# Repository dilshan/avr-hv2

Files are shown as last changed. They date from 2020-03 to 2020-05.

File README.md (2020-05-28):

AVR High Voltage Programmer 2
==========================

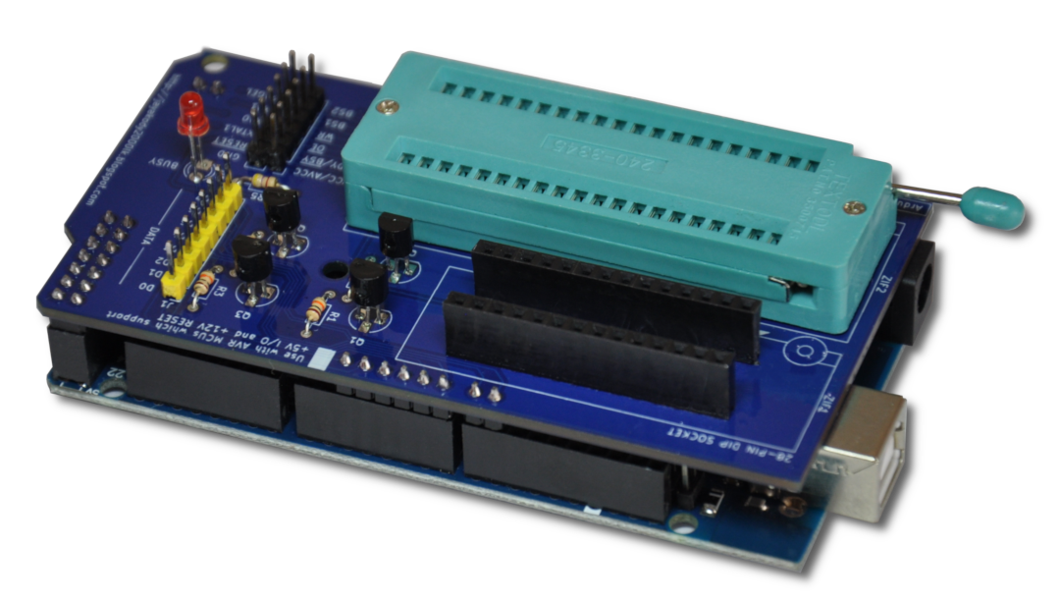
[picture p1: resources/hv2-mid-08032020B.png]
AVR-HV2 Prototype with Arduino MEGA board


*AVR-HV2* is *Arduino* based high voltage parallel programmer for *[AVR](https://www.microchip.com/design-centers/8-bit/avr-mcus)* microcontrollers. This programmer can read, write, and erase both flash memory and EEPROM. Also, this can use to set fuse bits of *AVR* MCUs. 

*AVR-HV2* programmer is designed as an *[Arduino Mega](https://www.arduino.cc/en/Main/ArduinoBoardMega2560)* shield. Dimensions of the *AVR-HV2* are similar to the *Arduino Mega* board. It can be powered using a power source connected to the *Arduino Mega* board. The suggested power source for this programmer is a 12V 1A DC power adapter. 

The control software of this programmer is design to work on both *Windows* and *Linux* operating systems. It supports the import and export of memory data in the Intel hex file format. The communication link between the programmer and the control software is established through the USB port. 

The current firmware and control software of this programmer supports most of the generally available *AVR* MCUs which including *ATmega8*, *ATmega328*, *ATmega32*, *ATmega16*, etc. The *AVR* MCUs with extended addressing modes are currently not supported. 

The PCB board used in this project is sponsored by the *[PCBWay](https://www.pcbway.com/)*. PCB of this project can directly order from *PCBWay* through this [link](https://www.pcbway.com/project/shareproject/AVR_High_Voltage_Programmer_2.html).

This is a certified open-source hardware project. All the design files, [documentation](https://github.com/dilshan/avr-hv2/wiki) and firmware source code are available to [download](https://github.com/dilshan/avr-hv2/releases) at the project source repository. All the content of this project are distributed under the terms of the following license:

- Hardware License: [CC BY 4.0](https://creativecommons.org/licenses/by/4.0/)
- Software License: [MIT](https://github.com/dilshan/avr-hv2/blob/master/LICENSE)
- Documentation License: [CC BY 4.0](https://creativecommons.org/licenses/by/4.0/)

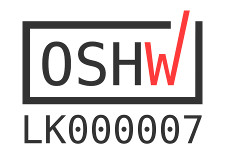
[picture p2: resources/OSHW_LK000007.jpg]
OSHW-LK000007 (https://certification.oshwa.org/lk000007.html)


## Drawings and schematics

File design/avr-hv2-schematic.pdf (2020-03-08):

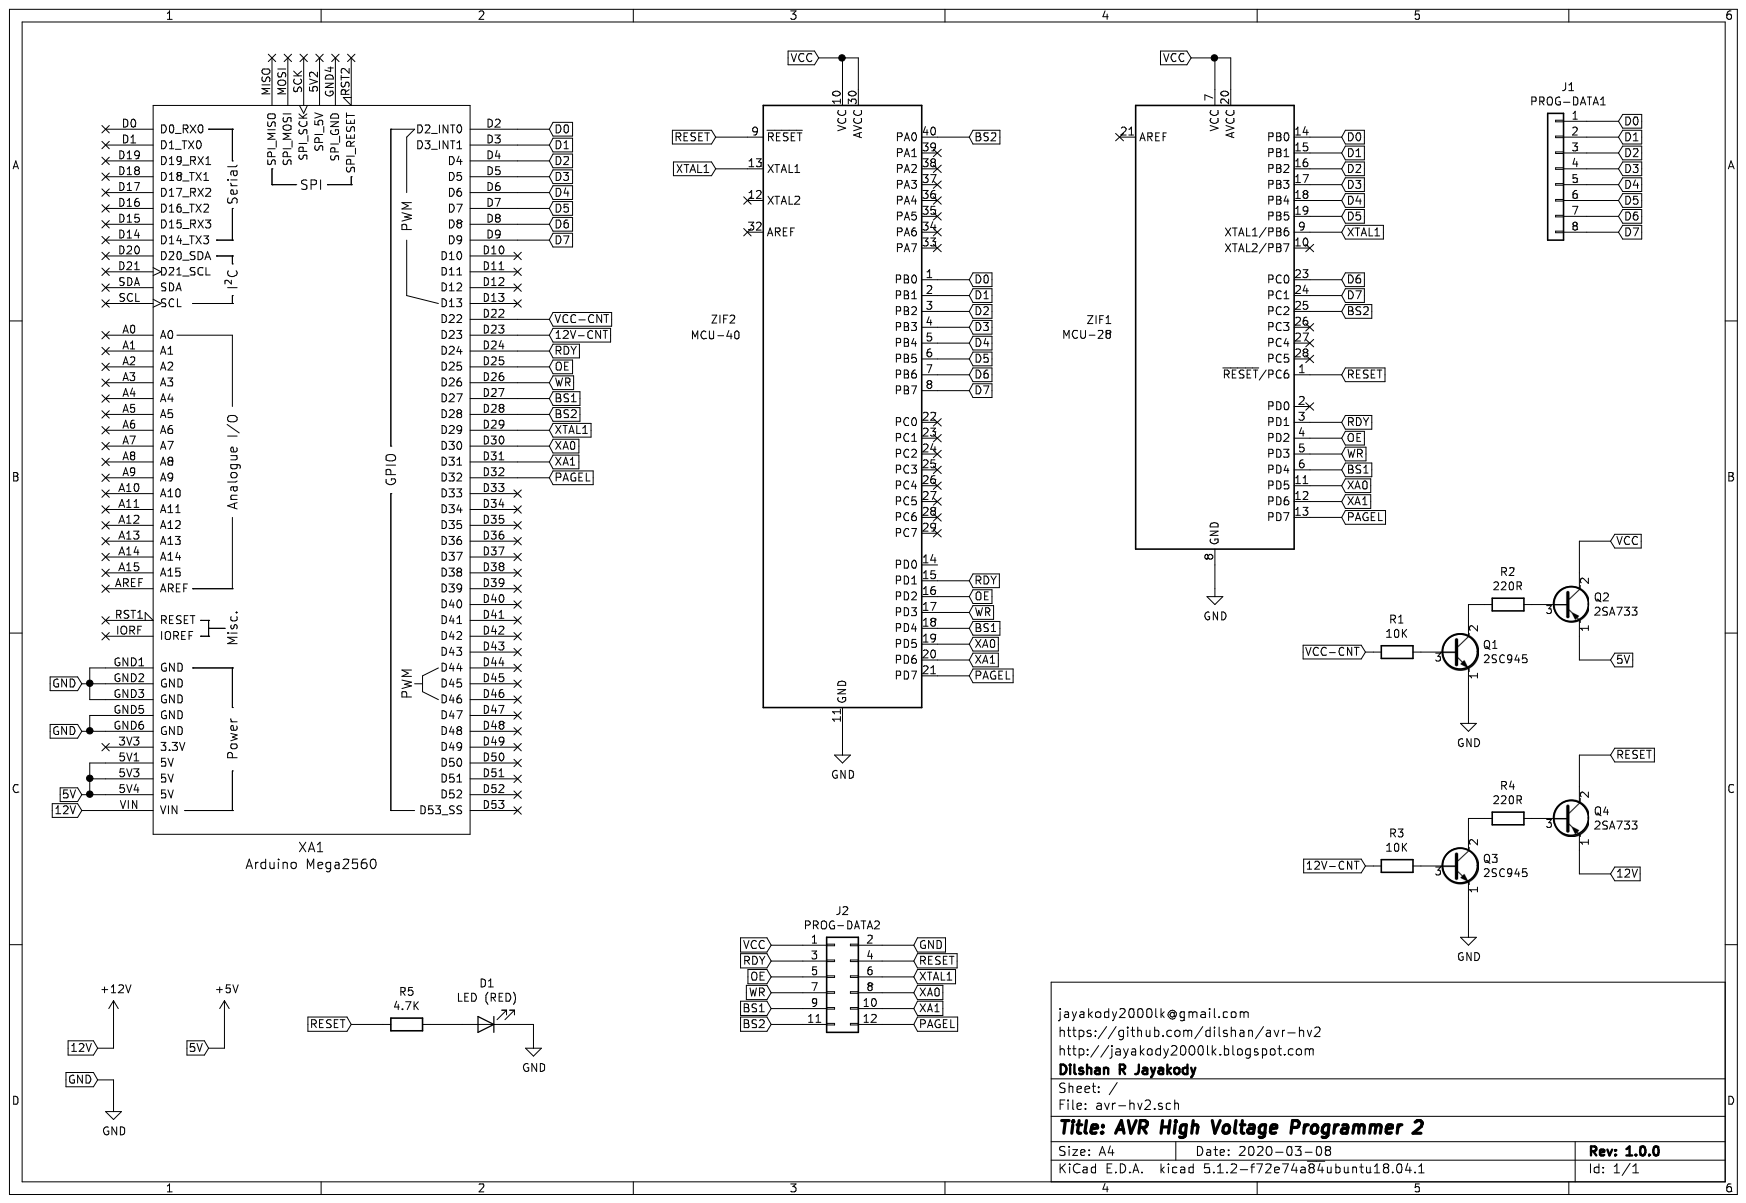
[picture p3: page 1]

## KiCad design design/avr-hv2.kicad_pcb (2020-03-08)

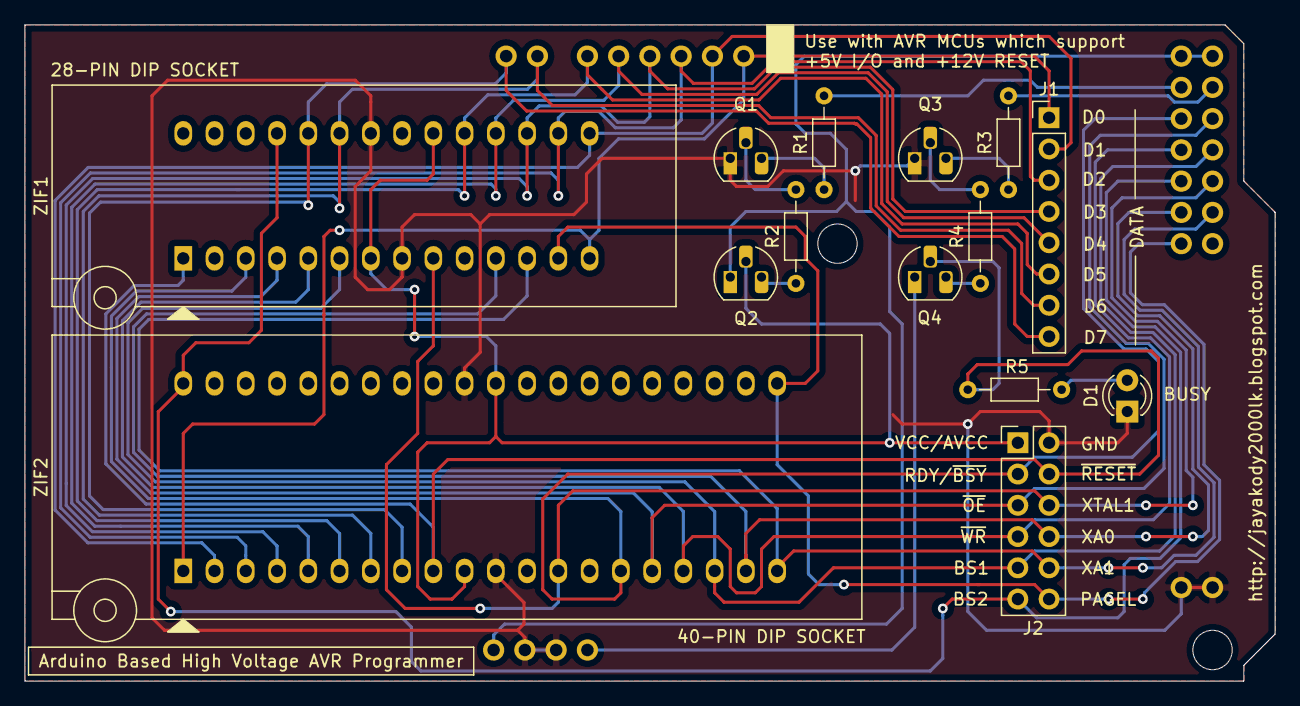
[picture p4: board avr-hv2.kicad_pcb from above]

Board: 2 copper layers, 101.6 x 53.3 mm, 15 parts (0 on the bottom side), 31 nets.

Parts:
D1: LED (RED); LED_D3.0mm
J1: PROG-DATA1; PinHeader_1x08_P2.54mm_Vertical
J2: PROG-DATA2; PinHeader_2x06_P2.54mm_Vertical
Q1, Q3: 2SC945; TO-92_HandSolder
Q2, Q4: 2SA733; TO-92_HandSolder
R1, R3: 10K; R_Axial_DIN0204_L3.6mm_D1.6mm_P7.62mm_Horizontal
R2, R4: 220R; R_Axial_DIN0204_L3.6mm_D1.6mm_P7.62mm_Horizontal
R5: 4.7K; R_Axial_DIN0204_L3.6mm_D1.6mm_P7.62mm_Horizontal
XA1: Arduino Mega2560; MEGA2560
ZIF1: MCU-28; DIP_Socket-28_W6.9_W7.62_W10.16_W12.7_W13.5_3M_228-4817-00-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
ZIF2: MCU-40; DIP_Socket-40_W11.9_W12.7_W15.24_W17.78_W18.5_3M_240-1280-0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

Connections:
5V: Q2.1, XA1.5V1, XA1.5V3, XA1.5V4
12V: Q4.1, XA1.VIN
12V-CNT: R3.2, XA1.D23
BS1: J2.9, XA1.D27, ZIF1.6, ZIF2.18
BS2: J2.11, XA1.D28, ZIF1.25, ZIF2.40
D0: J1.1, XA1.D2, ZIF1.14, ZIF2.1
D1: J1.2, XA1.D3, ZIF1.15, ZIF2.2
D2: J1.3, XA1.D4, ZIF1.16, ZIF2.3
D3: J1.4, XA1.D5, ZIF1.17, ZIF2.4
D4: J1.5, XA1.D6, ZIF1.18, ZIF2.5
D5: J1.6, XA1.D7, ZIF1.19, ZIF2.6
D6: J1.7, XA1.D8, ZIF1.23, ZIF2.7
D7: J1.8, XA1.D9, ZIF1.24, ZIF2.8
GND: D1.1, J2.2, Q1.1, Q3.1, XA1.GND2, XA1.GND3, XA1.GND5, XA1.GND6, ZIF1.8, ZIF1.22, ZIF2.11, ZIF2.31
unnamed: D1.2, R5.1
unnamed: Q1.2, R2.2
unnamed: Q1.3, R1.1
unnamed: Q2.3, R2.1
unnamed: Q3.2, R4.2
unnamed: Q3.3, R3.1
unnamed: Q4.3, R4.1
OE: J2.5, XA1.D25, ZIF1.4, ZIF2.16
PAGEL: J2.12, XA1.D32, ZIF1.13, ZIF2.21
RDY: J2.3, XA1.D24, ZIF1.3, ZIF2.15
RESET: J2.4, Q4.2, R5.2, ZIF1.1, ZIF2.9
VCC: J2.1, Q2.2, ZIF1.7, ZIF1.20, ZIF2.10, ZIF2.30
VCC-CNT: R1.2, XA1.D22
WR: J2.7, XA1.D26, ZIF1.5, ZIF2.17
XA0: J2.8, XA1.D30, ZIF1.11, ZIF2.19
XA1: J2.10, XA1.D31, ZIF1.12, ZIF2.20
XTAL1: J2.6, XA1.D29, ZIF1.9, ZIF2.13

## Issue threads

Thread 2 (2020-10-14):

FYI: repurposed to program ATtiny28 via ATmega4809 (on protoboard.)

WestfW, 2020-10-14:
(no, this isn't really an "issue.")

It happens that I have some ATtiny28 chips that I want to program.
These are only programmable via HVPP, and my STK500 doesn't seem to be working, so I looked around for something else that might be able to program it, and found your avr-hv2 project.

I based the hardware (built on a protoboard) on your project, plus the datasheet, plus some other HV programmers, and started with your firmware.  I don't think that much of it is left - the ATtiny28 works somewhat differently, I didn't try to make it more general, I used an ATmega4809 board as the programmer, and I implemented a more user-oriented communications protocol, but I wanted to thank you for publishing your project, since it was definitely easier to start working with it than to start from nothing...

Should you need to program a very old HVPP chip, it might be useful to look at.  It's here:  https://github.com/WestfW/Duino-hacks/tree/master/hvTiny28prog

Thanks!

dilshan, 2020-10-14:
Hello @WestfW.

Thank you for share this information.

I had limited experience with the ATTiny family because it is not much popular here (in _Sri Lanka_). At the time of this development, ATTiny chips are hard to find in the market. That's the main reason I skip ATTiny support.

It's good to have HVPP support programmer firmware for the ATTiny family. Most of the time, I need these HVPPs to recover the chips, which got "bricked" by wrong fuse settings.

Thank you! :+1:

Closed 2020-10-14.

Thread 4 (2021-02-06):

Atmega644p fuse fixing

mossana, 2021-02-06:
Hello
I programmer a atmega644p and set fuse cksel[3-0]=0001
And my arduino as isp can't detect chip again by avrdude
So can avr-hv2 solve problem or not ?
Thank you 😊 for your help

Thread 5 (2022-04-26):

Support for Attiny 2313a and 4313

thecky, 2022-04-26:
Hi,

is it possible to add the definitions for the:
 * Attiny 2313a
 * Attiny 4313

to the main-programm?

This both devices support HVPP and I would like to use avr-hv2 with this MCU.
The datasheet can be found here:
https://ww1.microchip.com/downloads/en/DeviceDoc/doc8246.pdf

Thank you.

W4DJW, 2023-09-08:
Hi,

Is it possible to add the definitions for the ATtiny28 L/V to the main-program?

This device supports HVPP and I would like to use the avr-hv2 with this MCU. Looking for the Flash Page size,  number of pages and Fuse bit updates. I'm not finding any info in the datasheet.

In addition, is there a way to update Fuse bytes from data I entered in the 'Configuration' tab?

Last thing, the 'Erase Chip' button appears to do nothing with respect to stored values. I can read the flash and get the same results with the chip in the socket or removed from the socket.

The ATtiny28 datasheet can be found here:

   https://ww1.microchip.com/downloads/en/DeviceDoc/doc1062.pdf

Thank you.

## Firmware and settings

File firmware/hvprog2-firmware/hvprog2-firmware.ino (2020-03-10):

/*==============================================================================

  Arduino based AVR High Voltage Programmer 2
  [https://github.com/dilshan/avr-hv2]

  Copyright (c) 2020 Dilshan R Jayakody [jayakody2000lk at gmail dot com]

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
  THE SOFTWARE IS PROVIDED "AS IS", WITHOUT WARRANTY OF ANY KIND, EXPRESS OR
  IMPLIED, INCLUDING BUT NOT LIMITED TO THE WARRANTIES OF MERCHANTABILITY,
  FITNESS FOR A PARTICULAR PURPOSE AND NONINFRINGEMENT. IN NO EVENT SHALL THE
  AUTHORS OR COPYRIGHT HOLDERS BE LIABLE FOR ANY CLAIM, DAMAGES OR OTHER
  LIABILITY, WHETHER IN AN ACTION OF CONTRACT, TORT OR OTHERWISE, ARISING FROM,
  OUT OF OR IN CONNECTION WITH THE SOFTWARE OR THE USE OR OTHER DEALINGS IN THE
  SOFTWARE.
==============================================================================*/

#define RX_BUFFER_SIZE  4

#define CMD_HANDSHAKE       'H'
#define CMD_VERSION         'V'
#define CMD_CHIP_SIGNATURE  'S'
#define CMD_GET_FUSE        'A'
#define CMD_GET_CALIBRATE   'L'
#define CMD_READ_FLASH      'R'
#define CMD_END             'E'
#define CMD_ERASE           'C'
#define CMD_WRITE_FLASH     'W'
#define CMD_WRITE_PAGE      'P'
#define CMD_READ_EEPROM     'T'
#define CMD_WRITE_EEPROM    'J'
#define CMD_WRITE_E2PAGE    'X'
#define CMD_SET_FUSE_LOW    'B'
#define CMD_SET_FUSE_HIGH   'I'
#define CMD_SET_FUSE_EXT    'K'
#define CMD_SET_FUSE_LOCK   'O'

#define PIN_VCC             22
#define PIN_12V             23

#define PIN_RDY             24
#define PIN_OE              25
#define PIN_WR              26
#define PIN_BS1             27
#define PIN_BS2             28
#define PIN_XTAL1           29
#define PIN_XA0             30
#define PIN_XA1             31
#define PIN_PAGEL           32

#define PIN_D0              2
#define PIN_D1              3
#define PIN_D2              4
#define PIN_D3              5
#define PIN_D4              6
#define PIN_D5              7
#define PIN_D6              8
#define PIN_D7              9

#define PROG_ENABLE0        PIN_BS1
#define PROG_ENABLE1        PIN_XA0
#define PROG_ENABLE2        PIN_XA1
#define PROG_ENABLE3        PIN_PAGEL

#define loadAddressLow(a) loadAddress(LOW, a)
#define loadAddressHigh(a) loadAddress(HIGH, a)

#define loadDataLow(d) loadData(LOW, d)
#define loadDataHigh(d) loadData(HIGH, d)

const unsigned char charMap[16] = {0x30, 0x31, 0x32, 0x33, 0x34, 0x35, 0x36, 0x37, 0x38, 0x39, 0x61, 0x62, 0x63, 0x64, 0x65, 0x66};

char commandBuffer[RX_BUFFER_SIZE];
unsigned char commandPos;
unsigned char lastCommand = ' ';

void resetBuffer()
{
  // Clear command buffer.
  for(unsigned char tmpPos = 0; tmpPos < RX_BUFFER_SIZE; tmpPos++)
  {
    commandBuffer[tmpPos] = 0;    
  }

  commandPos = 0;
}

void sendCommandResponse(char cmd, char error, char dataLen)
{
  char responseData[] = {'@', cmd, error, dataLen};
  Serial.write(responseData, 4);  
}

void byteToChr(unsigned char inByte, unsigned char *out)
{
  out[0] = charMap[(inByte >> 4) & 0x0F];
  out[1] = charMap[inByte & 0x0F];
}

void chrToByte(unsigned char *chrBuffer, unsigned char* byteData)
{
  byteData[0] = (((chrBuffer[0] < 58) ? (chrBuffer[0] - 48) : (chrBuffer[0]) - 87) << 4) 
  | ((chrBuffer[1] < 58) ? (chrBuffer[1] - 48) : (chrBuffer[1] - 87));
}

void chrToWord(unsigned char *chrBuffer, unsigned char* wordData)
{
  wordData[0] = (((chrBuffer[0] < 58) ? (chrBuffer[0] - 48) : (chrBuffer[0]) - 87) << 4) 
  | ((chrBuffer[1] < 58) ? (chrBuffer[1] - 48) : (chrBuffer[1] - 87));
  wordData[1] = (((chrBuffer[2] < 58) ? (chrBuffer[2] - 48) : (chrBuffer[2]) - 87) << 4) 
  | ((chrBuffer[3] < 58) ? (chrBuffer[3] - 48) : (chrBuffer[3] - 87));  
}

void chrToWriteWord(unsigned char *chrBuffer, unsigned char* wordData)
{
  wordData[0] = (((chrBuffer[0] < 58) ? (chrBuffer[0] - 48) : (chrBuffer[0]) - 87) << 4) 
  | ((chrBuffer[1] < 58) ? (chrBuffer[1] - 48) : (chrBuffer[1] - 87));
  wordData[1] = (((chrBuffer[2] < 58) ? (chrBuffer[2] - 48) : (chrBuffer[2]) - 87) << 4) 
  | ((chrBuffer[3] < 58) ? (chrBuffer[3] - 48) : (chrBuffer[3] - 87));  
  wordData[2] = (((chrBuffer[4] < 58) ? (chrBuffer[4] - 48) : (chrBuffer[4]) - 87) << 4) 
  | ((chrBuffer[5] < 58) ? (chrBuffer[5] - 48) : (chrBuffer[5] - 87));
}

void setDataPinMode(unsigned char value)
{
  pinMode(PIN_D0, value);
  pinMode(PIN_D1, value);
  pinMode(PIN_D2, value);
  pinMode(PIN_D3, value);
  pinMode(PIN_D4, value);
  pinMode(PIN_D5, value);
  pinMode(PIN_D6, value);
  pinMode(PIN_D7, value);
  
  delayMicroseconds(5);
}

void initProgramMode()
{
  setDataPinMode(INPUT);
  
  // Set Prog_enable pins to 0000.
  digitalWrite(PROG_ENABLE0, LOW);
  digitalWrite(PROG_ENABLE1, LOW);
  digitalWrite(PROG_ENABLE2, LOW);
  digitalWrite(PROG_ENABLE3, LOW);

  // Shutdown VCC and +12V
  digitalWrite(PIN_VCC, LOW);
  digitalWrite(PIN_12V, LOW);

  delayMicroseconds(25);

  // Apply 5V to target device.
  digitalWrite(PIN_VCC, HIGH);
  delayMicroseconds(50);

  // Apply +12V to target device.
  digitalWrite(PIN_12V, HIGH);

  // Wait before giving any parallel programming commands.
  delayMicroseconds(500);

  // Enable output and write modes.
  digitalWrite(PIN_OE, HIGH);
  digitalWrite(PIN_WR, HIGH);
  delayMicroseconds(50);
}

void resetProgramMode()
{
  // Power the device down by setting VCC and +12V to low.
  digitalWrite(PIN_VCC, LOW);
  digitalWrite(PIN_12V, LOW);

  // Reset command bits.
  digitalWrite(PIN_RDY, HIGH);
  digitalWrite(PIN_OE, LOW);
  digitalWrite(PIN_WR, LOW);
  digitalWrite(PIN_BS1, LOW);
  digitalWrite(PIN_BS2, LOW);
  digitalWrite(PIN_XTAL1, LOW);
  digitalWrite(PIN_XA0, LOW);
  digitalWrite(PIN_XA1, LOW);
  digitalWrite(PIN_PAGEL, LOW);
}

void loadCommand(unsigned char cmd)
{
  // Set XA1, XA0 to 1, 0.
  digitalWrite(PIN_XA0, LOW);
  digitalWrite(PIN_XA1, HIGH);

  // Set BS1 to 0.
  digitalWrite(PIN_BS1, LOW);

  // Set DATA with specified command.
  setDataPinMode(OUTPUT);  
  digitalWrite(PIN_D0, (cmd >> 0) & 0x01);
  digitalWrite(PIN_D1, (cmd >> 1) & 0x01);
  digitalWrite(PIN_D2, (cmd >> 2) & 0x01);
  digitalWrite(PIN_D3, (cmd >> 3) & 0x01);
  digitalWrite(PIN_D4, (cmd >> 4) & 0x01);
  digitalWrite(PIN_D5, (cmd >> 5) & 0x01);
  digitalWrite(PIN_D6, (cmd >> 6) & 0x01);
  digitalWrite(PIN_D7, (cmd >> 7) & 0x01);

  // Pulse XTAL1.
  delayMicroseconds(5);
  digitalWrite(PIN_XTAL1, HIGH);
  delayMicroseconds(5);
  digitalWrite(PIN_XTAL1, LOW);
  delayMicroseconds(5);
}

void loadAddress(unsigned char seg, unsigned char addr)
{
  // Set XA1, XA0 to 0, 0.
  digitalWrite(PIN_XA0, LOW);
  digitalWrite(PIN_XA1, LOW);

  // Set BS1 based on address HIGH or LOW.
  digitalWrite(PIN_BS1, seg);

  // Set DATA with specified address.
  setDataPinMode(OUTPUT);  
  digitalWrite(PIN_D0, (addr >> 0) & 0x01);
  digitalWrite(PIN_D1, (addr >> 1) & 0x01);
  digitalWrite(PIN_D2, (addr >> 2) & 0x01);
  digitalWrite(PIN_D3, (addr >> 3) & 0x01);
  digitalWrite(PIN_D4, (addr >> 4) & 0x01);
  digitalWrite(PIN_D5, (addr >> 5) & 0x01);
  digitalWrite(PIN_D6, (addr >> 6) & 0x01);
  digitalWrite(PIN_D7, (addr >> 7) & 0x01);

  // Pulse XTAL1.
  delayMicroseconds(5);
  digitalWrite(PIN_XTAL1, HIGH);
  delayMicroseconds(5);
  digitalWrite(PIN_XTAL1, LOW);
  delayMicroseconds(5);  
}

void loadData(unsigned char seg, unsigned char data)
{
  // Set BS1 based on data HIGH or LOW.
  digitalWrite(PIN_BS1, seg);
  
  // Set XA1, XA0 to 0, 1.
  digitalWrite(PIN_XA0, HIGH);  
  digitalWrite(PIN_XA1, LOW);

  // Set DATA.
  setDataPinMode(OUTPUT); 
  digitalWrite(PIN_D0, (data >> 0) & 0x01);
  digitalWrite(PIN_D1, (data >> 1) & 0x01);
  digitalWrite(PIN_D2, (data >> 2) & 0x01);
  digitalWrite(PIN_D3, (data >> 3) & 0x01);
  digitalWrite(PIN_D4, (data >> 4) & 0x01);
  digitalWrite(PIN_D5, (data >> 5) & 0x01);
  digitalWrite(PIN_D6, (data >> 6) & 0x01);
  digitalWrite(PIN_D7, (data >> 7) & 0x01);

  // Pulse XTAL1.
  delayMicroseconds(5);
  digitalWrite(PIN_XTAL1, HIGH);
  delayMicroseconds(5);
  digitalWrite(PIN_XTAL1, LOW);
  delayMicroseconds(5);  
}

void latchData()
{
  // Set BS1 to 1.
  digitalWrite(PIN_BS1, HIGH);

  // Pulse PAGEL.
  delayMicroseconds(5);
  digitalWrite(PIN_PAGEL, HIGH);
  delayMicroseconds(5);
  digitalWrite(PIN_PAGEL, LOW);
  delayMicroseconds(5);
}

unsigned char programPage()
{
  unsigned char writeTimeout = 0;
  
  // Pulse WR.
  delayMicroseconds(5);
  digitalWrite(PIN_WR, LOW);
  delayMicroseconds(5);
  digitalWrite(PIN_WR, HIGH);

  // Wait until RDY/BSY goes high.
  while(writeTimeout < 250)
  {
    delay(10);
    writeTimeout++;

    if(digitalRead(PIN_RDY) == HIGH)
    {
      writeTimeout = 0;
      break;      
    }
  }

  return (writeTimeout == 0) ? 0x30 : 0x31;
}

unsigned char readData()
{
  unsigned char retData;
  
  setDataPinMode(INPUT);
  retData = (digitalRead(PIN_D0) << 0) & 0x01;
  retData |= (digitalRead(PIN_D1) << 1) & 0x02;
  retData |= (digitalRead(PIN_D2) << 2) & 0x04;
  retData |= (digitalRead(PIN_D3) << 3) & 0x08;
  retData |= (digitalRead(PIN_D4) << 4) & 0x10;
  retData |= (digitalRead(PIN_D5) << 5) & 0x20;
  retData |= (digitalRead(PIN_D6) << 6) & 0x40;
  retData |= (digitalRead(PIN_D7) << 7) & 0x80;

  return retData;
}

void setup() 
{
  unsigned char clearPos, tempBuffer;
  
  // Set power pin modes.
  pinMode(PIN_VCC, OUTPUT);   // VCC/+5V output control.
  pinMode(PIN_12V, OUTPUT);   // +12V output control.

  // Set initial state of the power related I/O pins.
  digitalWrite(PIN_VCC, LOW);
  digitalWrite(PIN_12V, LOW);

  // Initialize serial interface.
  Serial.begin(115200);
  delayMicroseconds(55);

  // Sep pin modes and initial values.
  pinMode(PIN_RDY, INPUT);
  pinMode(PIN_OE, OUTPUT);
  pinMode(PIN_WR, OUTPUT);
  pinMode(PIN_BS1, OUTPUT);
  pinMode(PIN_BS2, OUTPUT);
  pinMode(PIN_XTAL1, OUTPUT);
  pinMode(PIN_XA0, OUTPUT);
  pinMode(PIN_XA1, OUTPUT);
  pinMode(PIN_PAGEL, OUTPUT);

  setDataPinMode(OUTPUT);
  resetProgramMode();

  // Clear data in serial RX buffer.
  while(Serial.available() > 0)
  {
    tempBuffer = Serial.read();
    if((++clearPos) > 250)
    {
      break;
    }
  }

  resetBuffer();
}

void readSignature(unsigned char* signature)
{
  unsigned char addrOffset = 0;
  
  // Enter device into programming mode.
  initProgramMode();  

  // Load Command 0000 1000.
  loadCommand(0x08);

  while(addrOffset < 3)
  {
    // Load Address Low Byte for signature 0.
    loadAddressLow(addrOffset);
  
    // Set OE to 0, and BS1 to 0.
    digitalWrite(PIN_OE, LOW);
    digitalWrite(PIN_BS1, LOW);
  
    // Read signature byte from DATA.
    signature[addrOffset] = readData();
  
    // Set OE to 1.
    digitalWrite(PIN_OE, HIGH);
    addrOffset++;
  }

  resetProgramMode();
}

void readFuseBytes(unsigned char* fuseConfig)
{
  // Enter device into programming mode.
  initProgramMode();

  // Load Command 0000 0100.
  loadCommand(0x04);

  // Reading Fuse Low byte. Set OE to 0, BS2 to 0 and BS1 to 0.
  digitalWrite(PIN_OE, LOW);
  digitalWrite(PIN_BS1, LOW);
  digitalWrite(PIN_BS2, LOW);
  fuseConfig[0] = readData();

  // Reading Fuse High byte. Set OE to 0, BS2 to 1 and BS1 to 1.
  digitalWrite(PIN_OE, LOW);
  digitalWrite(PIN_BS1, HIGH);
  digitalWrite(PIN_BS2, HIGH);
  fuseConfig[1] = readData();

  // Reading Fuse Extended byte. Set OE to 0, BS2 to 1, and BS1 to 0.
  digitalWrite(PIN_OE, LOW);
  digitalWrite(PIN_BS1, LOW);
  digitalWrite(PIN_BS2, HIGH);
  fuseConfig[2] = readData();

  // Reading Lock byte. Set OE to 0, BS2 to 0 and BS1 to 1.
  digitalWrite(PIN_OE, LOW);
  digitalWrite(PIN_BS1, HIGH);
  digitalWrite(PIN_BS2, LOW);
  fuseConfig[3] = readData();

  // Set OE to 1.
  digitalWrite(PIN_OE, HIGH);
  resetProgramMode();
}

unsigned char setLockFuse(unsigned char fuseVal)
{
  unsigned char fuseSetTimeout = 0;
  
  // Enter device into programming mode.
  initProgramMode();

  // Load Command 0010 0000.
  loadCommand(0x20);

  // Load Data Low Byte.
  loadDataLow(fuseVal);

  // Give WR a negative pulse.
  delayMicroseconds(5);
  digitalWrite(PIN_WR, LOW);
  delayMicroseconds(5);
  digitalWrite(PIN_WR, HIGH);

  // Wait until RDY/BSY goes high.
  while(fuseSetTimeout < 250)
  {
    delay(20);
    fuseSetTimeout++;

    if(digitalRead(PIN_RDY) == HIGH)
    {
      fuseSetTimeout = 0;
      break;      
    }
  }

  resetProgramMode();
  return (fuseSetTimeout == 0) ? 0x30 : 0x31;
}

unsigned char setFuseLow(unsigned char fuseVal)
{
  unsigned char fuseSetTimeout = 0;
  
  // Enter device into programming mode.
  initProgramMode();

  // Load Command 0100 0000.
  loadCommand(0x40);

  // Load Data Low Byte.
  loadDataLow(fuseVal);

  // Set BS1 to 0 and BS2 to 0.
  digitalWrite(PIN_BS1, LOW);
  digitalWrite(PIN_BS2, LOW);

  // Give WR a negative pulse.
  delayMicroseconds(5);
  digitalWrite(PIN_WR, LOW);
  delayMicroseconds(5);
  digitalWrite(PIN_WR, HIGH);

  // Wait until RDY/BSY goes high.
  while(fuseSetTimeout < 250)
  {
    delay(20);
    fuseSetTimeout++;

    if(digitalRead(PIN_RDY) == HIGH)
    {
      fuseSetTimeout = 0;
      break;      
    }
  }

  resetProgramMode();
  return (fuseSetTimeout == 0) ? 0x30 : 0x31;
}
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
void loop() 
{
  if(Serial.available() > 0)
  {
    char tempData= Serial.read();

    // Clear data buffer at the beginning of the next command.
    if(tempData == '~')
    {
      resetBuffer();
    }

    // Fill command buffer with incoming bytes.
    if(commandPos < 4)
    {
      commandBuffer[commandPos] = tempData;
      commandPos++; 
    }

    // Looking for end of command.
    if(tempData == '^')
    {
      delayMicroseconds(10);

      unsigned char tmpSignature[3] = {0,0,0};
      unsigned char sigData[6];

      unsigned char tmpFuse[4] = {0,0,0,0};
      unsigned char fuseData[8];

      unsigned char calibrationData[2];

      unsigned char inAddr[4];
      unsigned char inAddrWord[2];

      unsigned char outData[4];
      unsigned char outDataWord[2];

      unsigned char inWriteAddr[6];
      unsigned char inwriteData[3];

      unsigned char inWriteHighAddr[2];
      unsigned char inAddrByte[1];

      unsigned char inFuseAddr[2];
      unsigned char inFuseByte[1];

      unsigned char writeStatus;
      unsigned char fuseStatus;
      unsigned char eraseStatus;

      // Execute specified action based on the received command.
      switch(commandBuffer[1])
      {
        case CMD_HANDSHAKE:
          sendCommandResponse(CMD_HANDSHAKE, '0', '0');
          lastCommand = CMD_HANDSHAKE;
          break;
        case CMD_VERSION:
          sendCommandResponse(CMD_VERSION, '0', '8');
          // Submit version info at the end of the header.
          Serial.write("01.00.00");
          lastCommand = CMD_VERSION;
          break;
        case CMD_CHIP_SIGNATURE:
          // Read chip 3 byte chip signature.
          readSignature(tmpSignature); 

          // Convert byte to char.
          byteToChr(tmpSignature[0], sigData);
          byteToChr(tmpSignature[1], sigData + 2);
          byteToChr(tmpSignature[2], sigData + 4);

          // Submit chip signature at the end of the header.
          sendCommandResponse(CMD_CHIP_SIGNATURE, '0', '6');
          Serial.write(sigData, 6);
          lastCommand = CMD_CHIP_SIGNATURE;
          break;
        case CMD_GET_FUSE:
          // Read low, high, extended and lock fuse bytes.
          readFuseBytes(tmpFuse);

          // Convert byte to char
          byteToChr(tmpFuse[0], fuseData);
          byteToChr(tmpFuse[1], fuseData + 2);
          byteToChr(tmpFuse[2], fuseData + 4);
          byteToChr(tmpFuse[3], fuseData + 6);

          // Submit fuse configuration at the end of the header.
          sendCommandResponse(CMD_GET_FUSE, '0', '8');
          Serial.write(fuseData, 8);
          lastCommand = CMD_GET_FUSE;
          break;
        case CMD_GET_CALIBRATE:
          // Get calibration byte and convert to char.
          byteToChr(readCalibrationByte(), calibrationData);

          sendCommandResponse(CMD_GET_CALIBRATE, '0', '2');
          Serial.write(calibrationData, 2);
          lastCommand = CMD_GET_CALIBRATE;
          break;
        case CMD_READ_FLASH:
          // Read specified address of the flash memory.
          if(readCmdParam(4, inAddr) == 0)
          {
            // Address parameters are loaded successfully.
            chrToWord(inAddr, inAddrWord);
            readFlash(inAddrWord, outDataWord);

            // Convert byte to char
            byteToChr(outDataWord[0], outData);
            byteToChr(outDataWord[1], outData + 2);

            // Submit read data at the end of the header.
            sendCommandResponse(CMD_READ_FLASH, '0', '4');
            Serial.write(outData, 4);
          }
          else
          {
            // Address parameter loading is fail.
            sendCommandResponse(CMD_READ_FLASH, '0', '0');
          } 
           
          lastCommand = CMD_READ_FLASH;  
          break;   
        case CMD_END:
          // End current operation.
          digitalWrite(PIN_OE, HIGH);
          resetProgramMode();

          sendCommandResponse(CMD_END, '0', '0');
          lastCommand = CMD_END;
          break;   
        case CMD_ERASE:
          // Perform chip erase.
          eraseStatus = eraseChip();

          // Submit erase status at the end of the header.
          sendCommandResponse(CMD_ERASE, '0', '1');
          Serial.write(eraseStatus);
          lastCommand = CMD_ERASE;
          break;
        case CMD_WRITE_FLASH:
          // Write specified data into specified flash memory address.
          if(readCmdParam(6, inWriteAddr) == 0)
          {
            // Extract address low byte and data word. [addr][d1][d0]
            chrToWriteWord(inWriteAddr, inwriteData);
            writeFlash(inwriteData[0], inwriteData + 1);
          }
          
          // Send response of the write command.
          sendCommandResponse(CMD_WRITE_FLASH, '0', '0');          
          lastCommand = CMD_WRITE_FLASH;
          break;
        case CMD_WRITE_PAGE:  
          // Write flash page contents.       
          if(readCmdParam(2, inWriteHighAddr) == 0)
          {
            chrToByte(inWriteHighAddr, inAddrByte); 
            writeStatus = writePage(inAddrByte[0]);  

            // Send write status at the end of the header.
            sendCommandResponse(CMD_WRITE_PAGE, '0', '1');
            Serial.write(writeStatus);  
          }
          else
          {
            // Send fail response of the write page command.
            sendCommandResponse(CMD_WRITE_PAGE, '0', '0');   
          }
                 
          lastCommand = CMD_WRITE_PAGE;
          break;
        case CMD_READ_EEPROM:
          // Read specified address of the EEPROM.
          if(readCmdParam(4, inAddr) == 0)
          {
            // Address parameters are loaded successfully.
            chrToWord(inAddr, inAddrWord);
            outDataWord[0] = readEEPROM(inAddrWord);

            // Convert byte to char
            byteToChr(outDataWord[0], outData);

            // Submit EEPROM data at the end of the header.
            sendCommandResponse(CMD_READ_EEPROM, '0', '2');
            Serial.write(outData, 2);
          }
          else
          {
            // Address parameter loading is fail.
            sendCommandResponse(CMD_READ_EEPROM, '0', '0');
          }
          
          lastCommand = CMD_READ_EEPROM;
          break;
        case CMD_WRITE_EEPROM:
          // Write specified data into specified EEPROM address.
          if(readCmdParam(6, inWriteAddr) == 0)
          {
            // Extract address word and data byte. [d0][addr1][addr0]
            chrToWriteWord(inWriteAddr, inwriteData);
            writeEEPROM(inwriteData, inwriteData[2]);
          }
          
          // Send response of the write command.
          sendCommandResponse(CMD_WRITE_EEPROM, '0', '0');          
          lastCommand = CMD_WRITE_EEPROM;
          break;
        case CMD_WRITE_E2PAGE:
          // Perform EEPROM page write.
          writeStatus = writeE2PROMPage();

          // Submit write status at the end of the header.
          sendCommandResponse(CMD_WRITE_E2PAGE, '0', '1');
          Serial.write(writeStatus);
          lastCommand = CMD_WRITE_E2PAGE;
          break;
        case CMD_SET_FUSE_LOW:
          // Set fuse low byte.
          if(readCmdParam(2, inFuseAddr) == 0)
          {
            chrToByte(inFuseAddr, inFuseByte); 
            fuseStatus = setFuseLow(inFuseByte[0]);

            // Send update status at the end of the header.
            sendCommandResponse(CMD_SET_FUSE_LOW, '0', '1');
            Serial.write(fuseStatus);
          }
          else
          {
            // Send fail response of the set fuse low byte command.
            sendCommandResponse(CMD_SET_FUSE_LOW, '0', '0');   
          }
          
          lastCommand = CMD_SET_FUSE_LOW;
          break;
        case CMD_SET_FUSE_HIGH:
          // Set fuse high byte.
          if(readCmdParam(2, inFuseAddr) == 0)
          {
            chrToByte(inFuseAddr, inFuseByte); 
            fuseStatus = setFuseHigh(inFuseByte[0]);

            // Send update status at the end of the header.
            sendCommandResponse(CMD_SET_FUSE_HIGH, '0', '1');
            Serial.write(fuseStatus);
          }
          else
          {
            // Send fail response of the set fuse high byte command.
            sendCommandResponse(CMD_SET_FUSE_HIGH, '0', '0');   
          }
          
          lastCommand = CMD_SET_FUSE_HIGH;
          break;
        case CMD_SET_FUSE_EXT:
          // Set extended fuse byte.
          if(readCmdParam(2, inFuseAddr) == 0)
          {
            chrToByte(inFuseAddr, inFuseByte); 
            fuseStatus = setFuseExtended(inFuseByte[0]);
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

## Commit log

2020-03-08 Initial version of the AVR-HV2.
    [avr-hv2.kicad_pcb, avr-hv2.sch]
2020-03-08 Update readme file with prototype image.
2020-03-08 Fixed issues in prototype photograph.
2020-03-10 Add support to configure individual fuse bytes.
2020-03-10 Fix typo in fuse configuration comment.
    [hvprog2-firmware.ino]
2020-03-12 Update README.md
    Add PCBWay order link.

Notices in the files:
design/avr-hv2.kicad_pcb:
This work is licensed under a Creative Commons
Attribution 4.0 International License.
